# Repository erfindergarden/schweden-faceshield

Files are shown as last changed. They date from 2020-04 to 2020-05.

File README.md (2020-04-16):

# Git repo für das Münchener SchwedenFaceshield (Maker VS. Virus Hub München)

* [Hauptinformationsseite für München: https://forums.erfindergarden.de/t/faceshield-angebot-im-makervsvirus-hubmuenchen/538](https://forums.erfindergarden.de/t/faceshield-angebot-im-makervsvirus-hubmuenchen/538)
* [Sammelstellen: https://forums.erfindergarden.de/t/hubmuenchen-makervs-virus-sammelstellen/539](https://forums.erfindergarden.de/t/hubmuenchen-makervs-virus-sammelstellen/539)

# Münchener Schweden
Single STL sind unter: Muenchener-Schwede-888/STL-Single
[Cura-Stacked Anleitung](Muenchener-Schwede-888/Cura-Stacked/README.md)

# Attribution:
Der Schwede 888 / 3x8  (nach 3dverkstan)  by postiman on Thingiverse: [https://www.thingiverse.com/thing:4261985](https://www.thingiverse.com/thing:4261985)

# Sonstige Links:
* [Allgemeine Informationen, wie mitmachen: https://www.makervsvirus.org/de/](https://www.makervsvirus.org/de/)
* [FAQ: https://www.makervsvirus.org/faq](https://www.makervsvirus.org/faq)
* [Guides: https://www.makervsvirus.org/guides](https://www.makervsvirus.org/guides)
* [Begleitschreiben ist hier zu finden: http://www.download-makervsvirus.de/](http://www.download-makervsvirus.de/)
* [Modelle: http://www.download-makervsvirus.de/](http://www.download-makervsvirus.de/) Achtung: bitte für den Hub München nur die oben unter "Modelle" genannten drucken - hiermit wird sichergestellt das in München die gleichen teile produziert werden. Wir haben uns auf den Lochabstand 888/3x8 geeinigt.

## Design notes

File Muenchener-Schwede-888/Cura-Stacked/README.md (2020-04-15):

## Cura Einstellungen für Stacks aus PETG

Wichtig: Vor Import des .3mf files in Cura unter Preferences->Configure Cura... die Option "Automatically drop models to the build plate" deaktivieren!

Falls die Teile sich nicht voneinander lösen lassen: Support Line Width reduzieren.
Falls Support nicht ordentlich abgelegt wird: Support Speed reduzieren.

### 0,6mm Nozzle

##### Quality
* Layer Height: 			0,4   mm
* Line Width:   			0,667 mm
* Support Line Width: 		0,25  mm

##### Shell
* Z-Seam Alignment:		User Specified (-> dann startet der Druck so, dass keine Travels notwendig sind)
* Z Seam X:					-80 mm
* Z Seam Y:					48,5 mm
* Z Seam Relative:			ja

##### Speed
* so schnell wie mit dem jeweiligen Drucker sinnvoll, ich setze alles auf 35mm/s
* Support Speed:  so langsam, dass das Supportlayer sauber abgelegt wird

##### Support
* generate Support:		
  * nein ( -> support wird durch zusätzliches Teil erzeugt),
  * (ja, falls Support stattdessen von Cura erzeugt werden soll)
* Support placement:		everywhere
* Support Overhang Angle:	85 °
* Support Pattern:			Concentric
* Support Line Distance:	1,1 mm
* Support Z Distance:		0 mm
* Support Join Distance:	0,25 mm
* Support Horizontal Exp.:	-0,45 mm

### 0,4mm Nozzle

##### Quality
* Layer Height: 			0,35   mm
* Line Width:   			0,5 mm
* Support Line Width: 		0,25  mm

##### Shell
* Z-Seam Alignment:		User Specified (-> dann startet der Druck so, dass keine Travels notwendig sind)
* Z Seam X:					-80 mm
* Z Seam Y:					48,5 mm
* Z Seam Relative:			ja

##### Speed
* so schnell wie mit dem jeweiligen Drucker sinnvoll, ich setze alles auf 35mm/s
* Support Speed:  so langsam, dass das Supportlayer sauber abgelegt wird

##### Support
* generate Support:		
  * nein ( -> support wird durch zusätzliches Teil erzeugt),
  * (ja, falls Support stattdessen von Cura erzeugt werden soll)
* Support placement:		everywhere
* Support Overhang Angle:	85 °
* Support Pattern:			Concentric
* Support Line Distance:	1,1 mm
* Support Z Distance:		0 mm
* Support Join Distance:	0,25 mm
* Support Horizontal Exp.:-0,45 mm

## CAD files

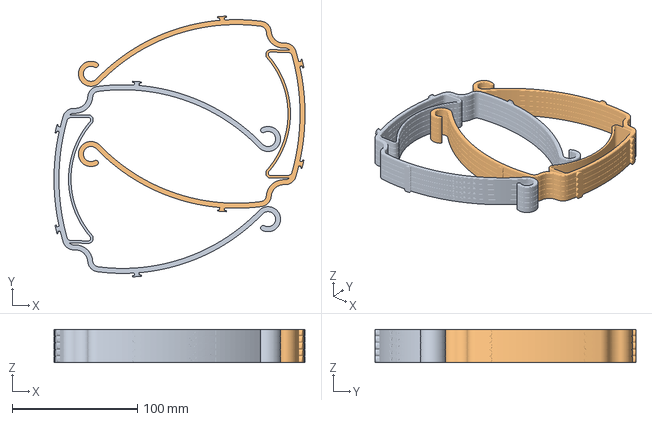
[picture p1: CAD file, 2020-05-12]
Muenchener-Schwede-888/Cura-Stacked/Stacked-Muenchener-Schwede888byAvG-V3_LineWidth0-5mm_PLA_offen_X2.3mf
200.3 x 208.2 x 26.6 mm

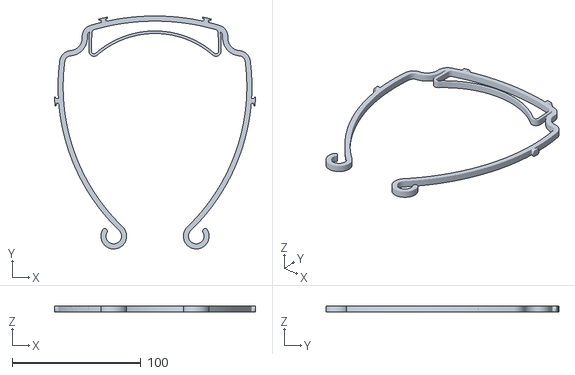
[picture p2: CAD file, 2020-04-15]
Muenchener-Schwede-888/STL-Single/0,4mm Nozzle/Muenchener-Schwede888byAvG-V3_LineWidth0-5mm_PETG_offen.STL
156.1 x 180.8 x 5.00

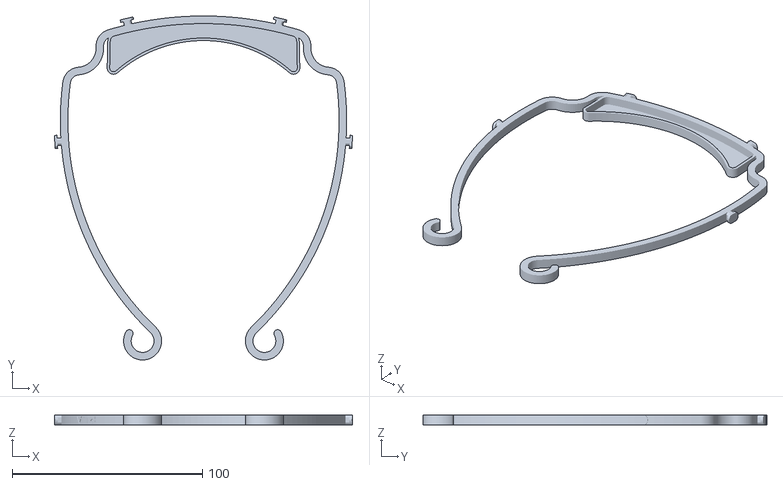
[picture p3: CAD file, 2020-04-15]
Muenchener-Schwede-888/STL-Single/0,6mm Nozzle/Muenchener-Schwede888byAvG-V3_LineWidth0-667mm_PLA_geschlossen.STL
156.8 x 180.8 x 5.00

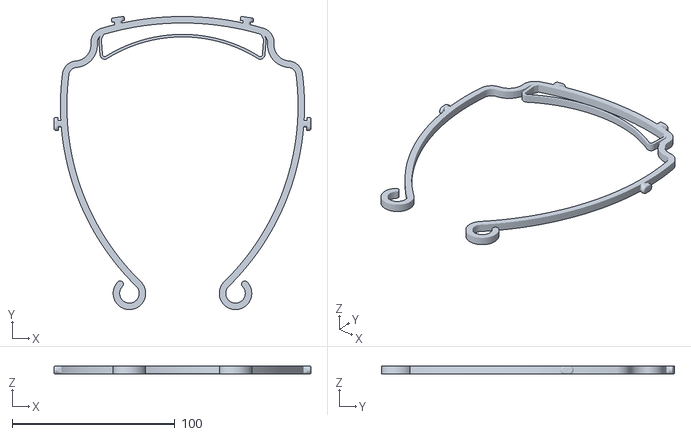
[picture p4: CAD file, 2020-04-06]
Other-Design/Neuer_Schwede_888_x1.stl
157.9 x 180.1 x 5.10

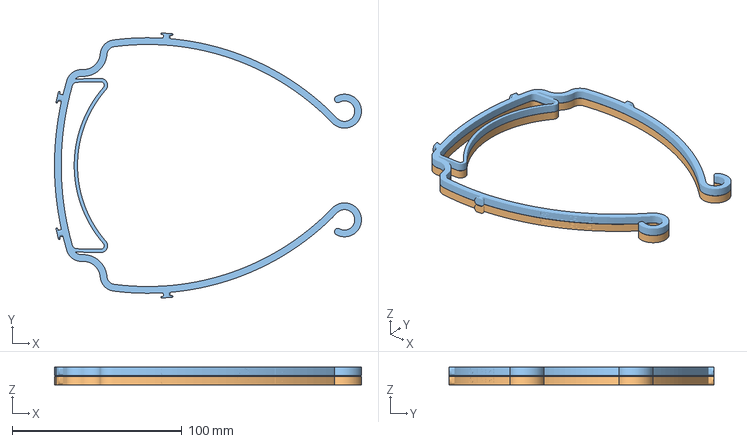
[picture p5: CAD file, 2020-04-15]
Muenchener-Schwede-888/Cura-Stacked/Stacked-Muenchener-Schwede888byAvG-V3_LineWidth0-5mm_PETG_offen_X2.3mf
180.8 x 156.1 x 10.3 mm

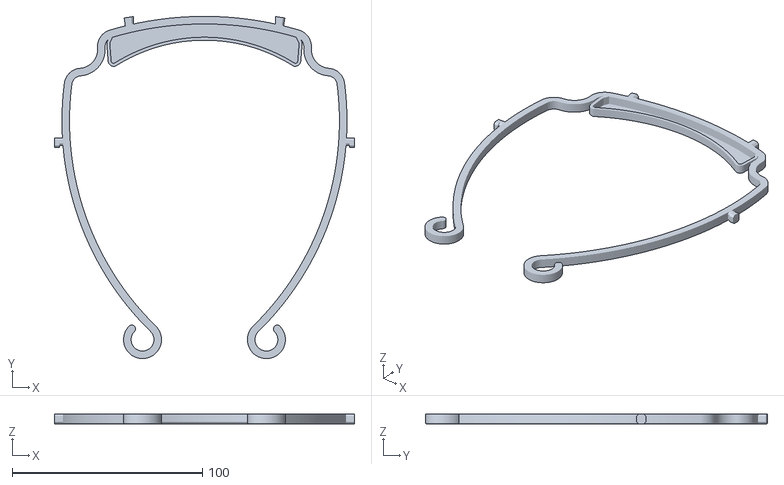
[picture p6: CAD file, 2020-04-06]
Other-Design/Der_Schwede_888_x1.stl
157.8 x 180.1 x 5.00

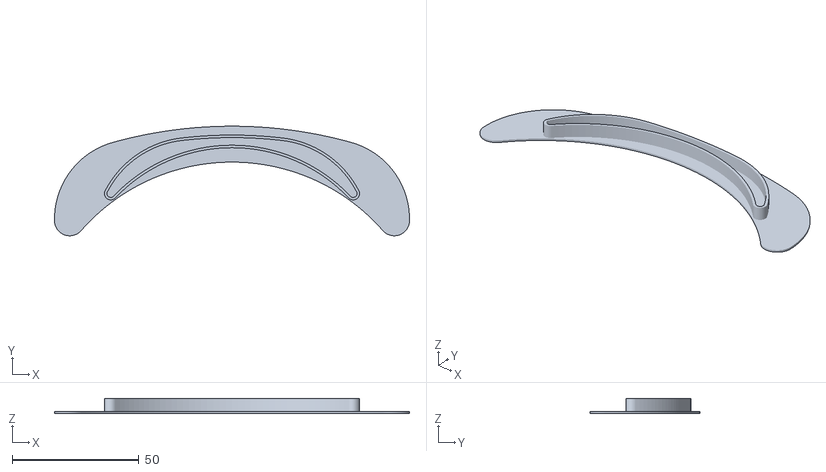
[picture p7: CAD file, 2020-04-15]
Muenchener-Schwede-888/STL-Single/0,4mm Nozzle/Muenchener-Schwede888byAvG-V3-Deckel_LineWidth0-5mm.STL
140.0 x 43.2 x 5.80

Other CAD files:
Muenchener-Schwede-888/STL-Single/0,4mm Nozzle/Muenchener-Schwede888byAvG-V3_LineWidth0-5mm_PLA_offen.STL
Muenchener-Schwede-888/STL-Single/0,6mm Nozzle/Muenchener-Schwede888byAvG-V3_LineWidth0-667mm_PETG_offen.STL
Muenchener-Schwede-888/Cura-Stacked/Stacked-Muenchener-Schwede888byAvG-V3_LineWidth0-667mm_PETG_offen_X2.3mf
Muenchener-Schwede-888/STL-Single/0,4mm Nozzle/Muenchener-Schwede888byAvG-V3_LineWidth0-5mm_PETG_geschlossen.STL
Muenchener-Schwede-888/STL-Single/0,6mm Nozzle/Muenchener-Schwede888byAvG-V3_LineWidth0-667mm_PLA_offen.STL
Muenchener-Schwede-888/STL-Single/0,4mm Nozzle/Muenchener-Schwede888byAvG-V3_LineWidth0-5mm_PLA_geschlossen.STL
Muenchener-Schwede-888/STL-Single/0,6mm Nozzle/Muenchener-Schwede888byAvG-V3_LineWidth0-667mm_PETG_geschlossen.STL
Muenchener-Schwede-888/STL-Single/0,6mm Nozzle/Muenchener-Schwede888byAvG-V3-Deckel_LineWidth0-667mm.STL

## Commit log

2020-04-06 added the STLs
    [Der_Schwede_888_x1.stl, Neuer_Schwede_888_x1.stl]
2020-04-15 First upload of Schwede V3
    [Schwede888byAvG-V3-Deckel_LineWidth0-5mm.STL, Schwede888byAvG-V3_LineWidth0-5mm_PETG_geschlossen.STL, Schwede888byAvG-V3_LineWidth0-5mm_PETG_offen.STL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]
2020-04-15 München Schwede für 0,6mm Nozzle
    [Schwede888byAvG-V3-Deckel_LineWidth0-667mm.STL, Schwede888byAvG-V3_LineWidth0-667mm_PETG_geschlossen.STL, Schwede888byAvG-V3_LineWidth0-667mm_PETG_offen.STL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]
2020-04-15 small stacks for testing
    [Schwede888byAvG-V3_LineWidth0-5mm_PETG_offen_X2.3mf, Schwede888byAvG-V3_LineWidth0-667mm_PETG_offen_X2.3mf]
2020-04-16 Clears up structure, remove empty files
    - Renamed to Muenchener
    - Removing empty files
    - Linking MD files
    [Der_Schwede_888_x1.stl, Muenchener-Schwede888byAvG-V3-Deckel_LineWidth0-5mm.STL, Muenchener-Schwede888byAvG-V3-Deckel_LineWidth0-667mm.STL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]
2020-05-12 Ads stacked PLA version for nozzle 0.4 and 0.6
    [Stacked-Muenchener-Schwede888byAvG-V3_LineWidth0-5mm_PLA_offen_X2.3mf]
